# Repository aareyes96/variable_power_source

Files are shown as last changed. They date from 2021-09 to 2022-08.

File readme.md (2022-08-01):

# Variable Power Source

An essential tool in an electronics workshop is a Variable Power Source. This must regulate current and voltage delivered in addition to having protections against short circuits.

This Variable Power Supply is built by modifying an old PC ATX power supply and based on a tutorial made by Cuban electronics [here](http://cubaelectronica.blogspot.com/2017/06/hacer-fuente-atx-pc-variable-desde-1-28.html) where the modifications that need to be made to the PC ATX Power Supply are explained.

>### _**Here the microcontroller control board is made to achieve better control precision. It also provides a real-time current, voltage and power measurement.**_

## Features

* Complete range ( from 0V to 30V and 0A to 15A ) control with a maximum precision for a wide range.
* Fast short-circuit protection.
* Minimum modifications made to ATX Power Supply.
* Nice and clear interface.
* ~~5V (of Standby supply) for USB plug~~ (Not supported yet).
* small design (all into ATX chassis) by choice.

## What do you need ?

* Bluepill (STM32F103C8T6 microcontroller based board).
* OLED 128x64 0.96"(SSD1306 based)  ~~display or LCD 16x2 Display~~(Actually not supported).
* A rotary encoder with central Button.
* LM324 IC.
* BD139 Transistor.
* Some others common components (Resistors and Capacitors, LEDs, Connectors, a little switch, etc).

## Softwares Used

* STM32CubeIDE 1.3.0 (Firmware and Debug).
* KiCAD (Schematic and PCB).
* NI Multisim 14.0 (Simulations).

## **Important Note**

>PCB layout is made to do at home (DIY). They are not optimized to manufacture with a PCB manufacturing company like JLCPCB or others.

## Preview

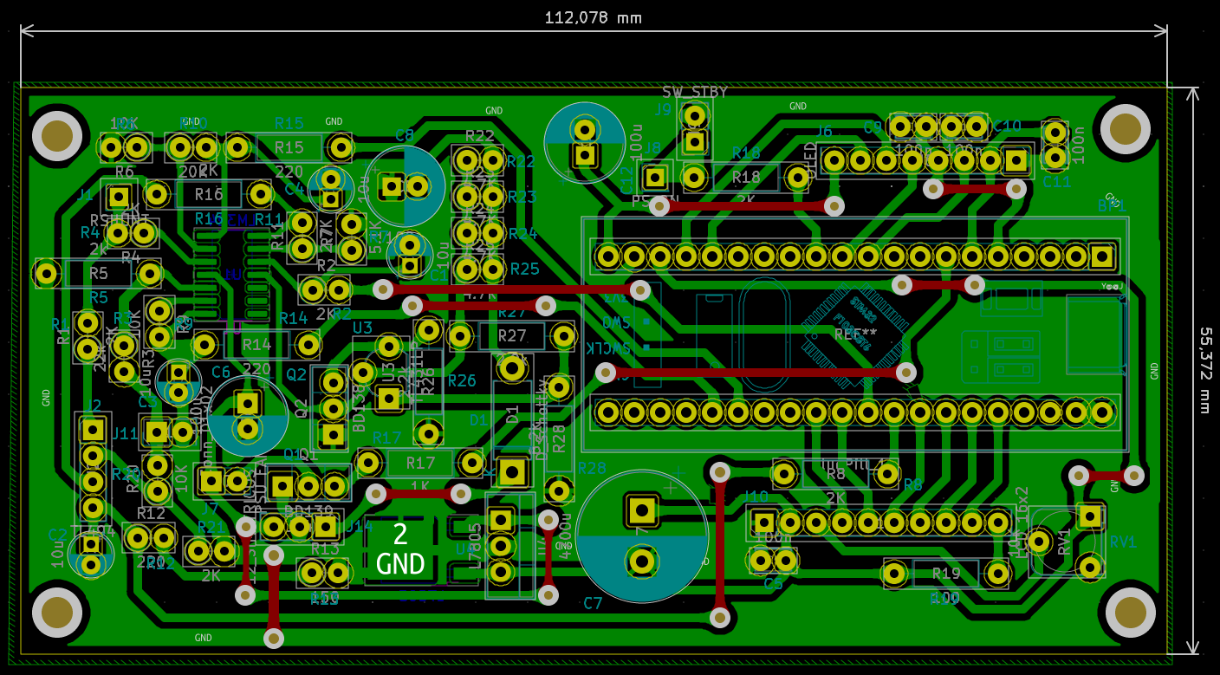
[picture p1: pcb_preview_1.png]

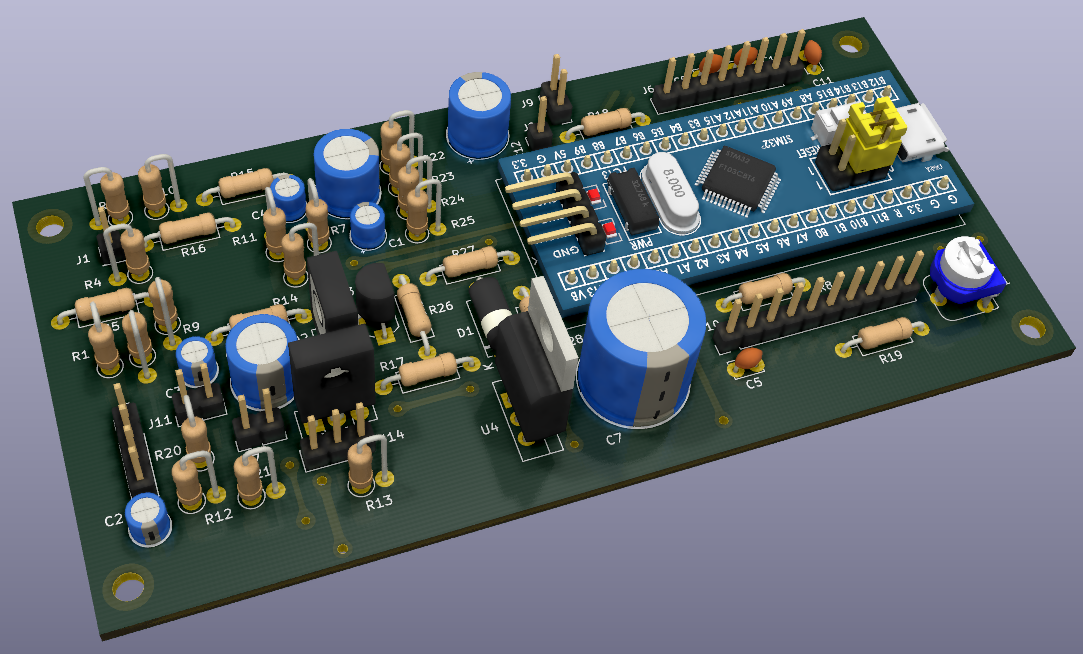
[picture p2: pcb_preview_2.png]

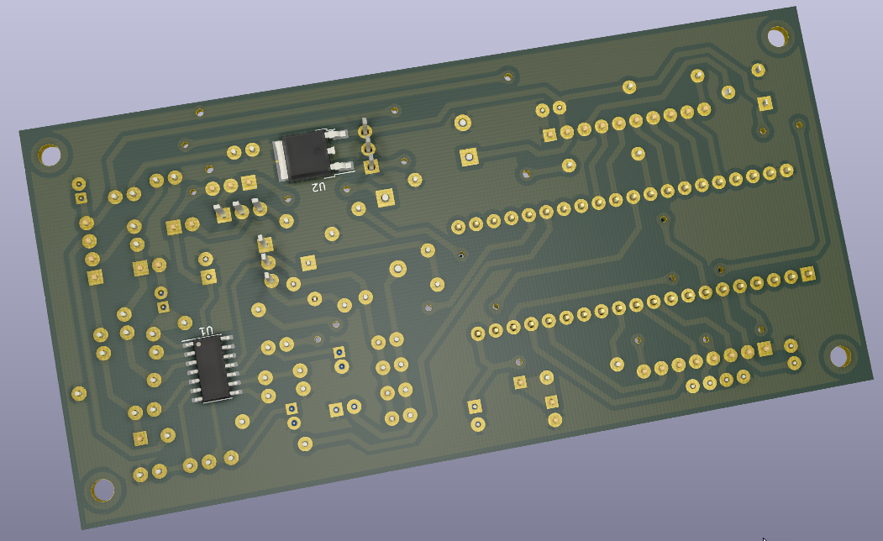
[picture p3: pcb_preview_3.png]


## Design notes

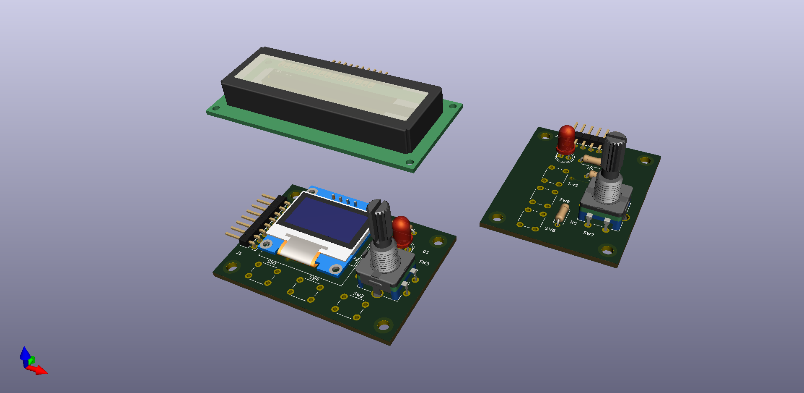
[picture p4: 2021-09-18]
PSU_displays/encoder.png

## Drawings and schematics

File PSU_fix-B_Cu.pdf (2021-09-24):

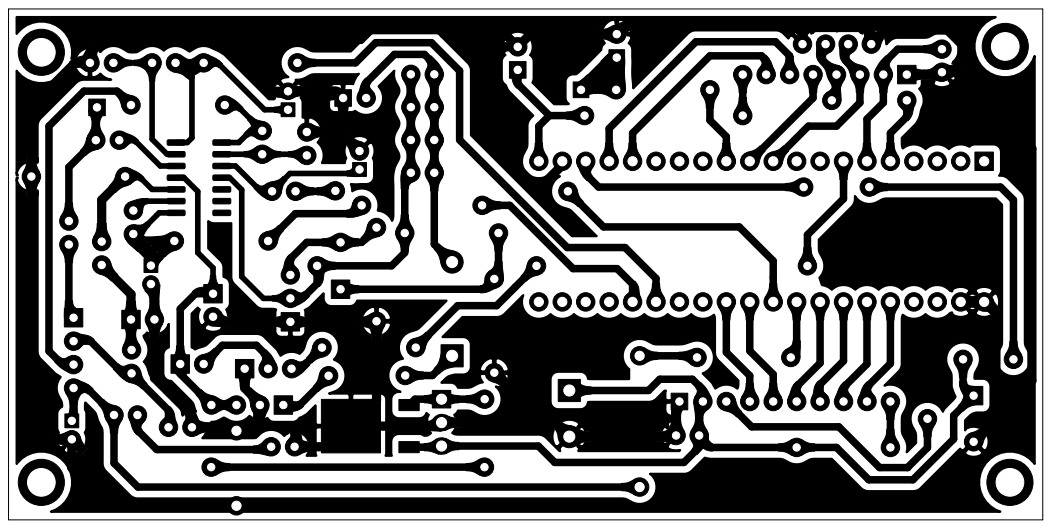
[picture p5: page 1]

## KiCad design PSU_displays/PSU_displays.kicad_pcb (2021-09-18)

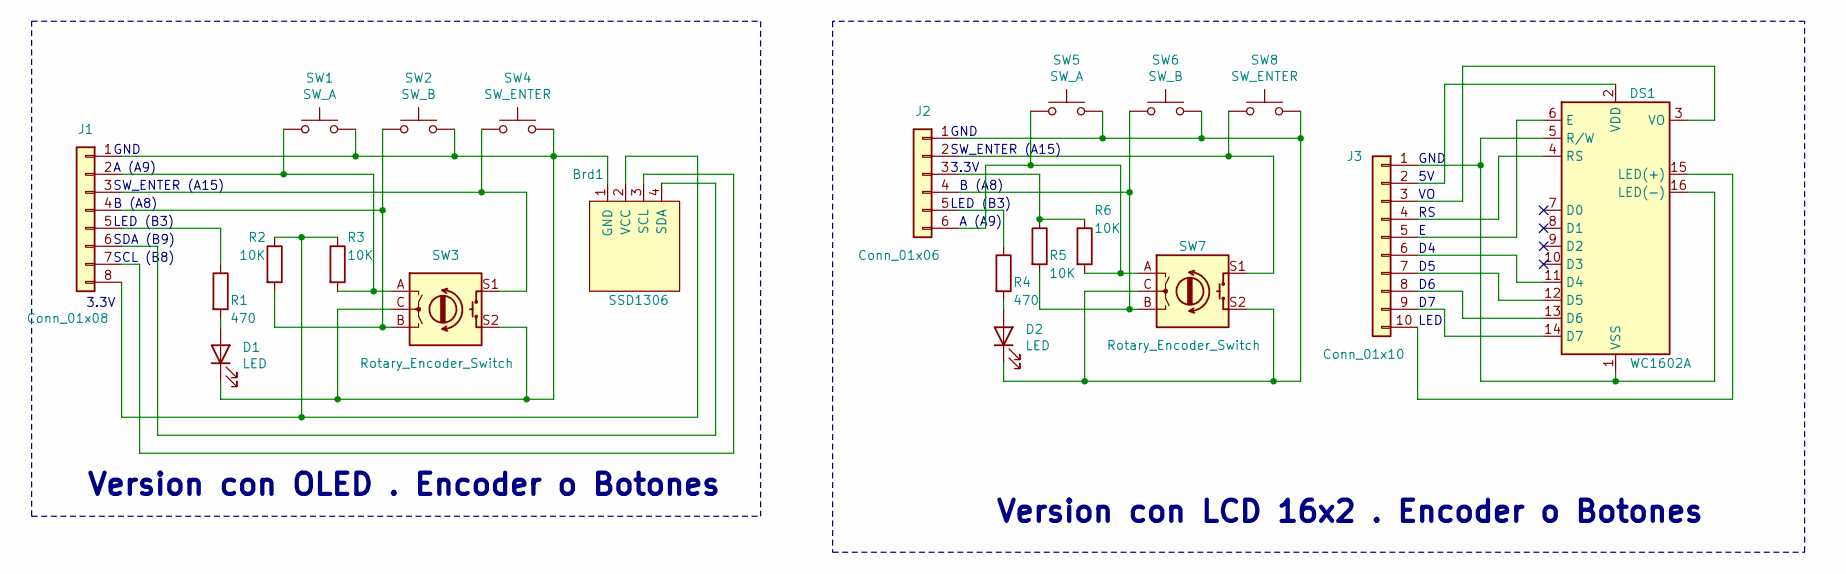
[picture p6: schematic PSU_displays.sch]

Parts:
Brd1: SSD1306; 128x64OLED
D1, D2: LED; LED_D5.0mm
DS1: WC1602A
J1: Conn_01x08; PinHeader_1x08_P2.54mm_Horizontal
J2: Conn_01x06; PinHeader_1x06_P2.54mm_Horizontal
J3: Conn_01x10; PinHeader_1x10_P2.54mm_Horizontal
R1, R4: 470; R_Axial_DIN0207_L6.3mm_D2.5mm_P7.62mm_Horizontal
R2, R3, R5, R6: 10K; R_Axial_DIN0207_L6.3mm_D2.5mm_P7.62mm_Horizontal
SW1, SW5: SW_A; SW_PUSH_6mm
SW2, SW6: SW_B; SW_PUSH_6mm
SW3, SW7: Rotary_Encoder_Switch; RotaryEncoder_Alps_EC11E-Switch_Vertical_H20mm_CircularMoun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
SW4, SW8: SW_ENTER; SW_PUSH_6mm

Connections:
unnamed: Brd1.1 (GND), D1.1 (K), J1.1, SW1.2, SW2.2, SW3.C, SW3.S2, SW4.2
unnamed: Brd1.2 (VCC), J1.8, R2.1, R3.1
unnamed: Brd1.3 (SCL), J1.7
unnamed: Brd1.4 (SDA), J1.6
unnamed: D1.2 (A), R1.2
unnamed: D2.1 (K), J2.1, SW5.2, SW6.2, SW7.C, SW7.S2, SW8.2
unnamed: D2.2 (A), R4.2
unnamed: DS1.1 (VSS), DS1.5 (R/W), DS1.16 (LED(-)), J3.1
unnamed: DS1.2 (VDD), J3.2
unnamed: DS1.3 (VO), J3.3
unnamed: DS1.4 (RS), J3.4
unnamed: DS1.6 (E), J3.5
unnamed: DS1.11 (D4), J3.6
unnamed: DS1.12 (D5), J3.7
unnamed: DS1.13 (D6), J3.8
unnamed: DS1.14 (D7), J3.9
unnamed: DS1.15 (LED(+)), J3.10
unnamed: J1.2, R3.2, SW1.1, SW3.A
unnamed: J1.3, SW3.S1, SW4.1
unnamed: J1.4, R2.2, SW2.1, SW3.B
unnamed: J1.5, R1.1
unnamed: J2.2, SW7.S1, SW8.1
unnamed: J2.3, R5.1, R6.1
unnamed: J2.4, R5.2, SW6.1, SW7.B
unnamed: J2.5, R4.1
unnamed: J2.6, R6.2, SW5.1, SW7.A

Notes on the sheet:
Version con OLED . Encoder o Botones
Version con LCD 16x2 . Encoder o Botones
3.3V
SCL (B8)
LED (B3)
B (A8)
SW_ENTER (A15)
A (A9)
GND
LED
SDA (B9)

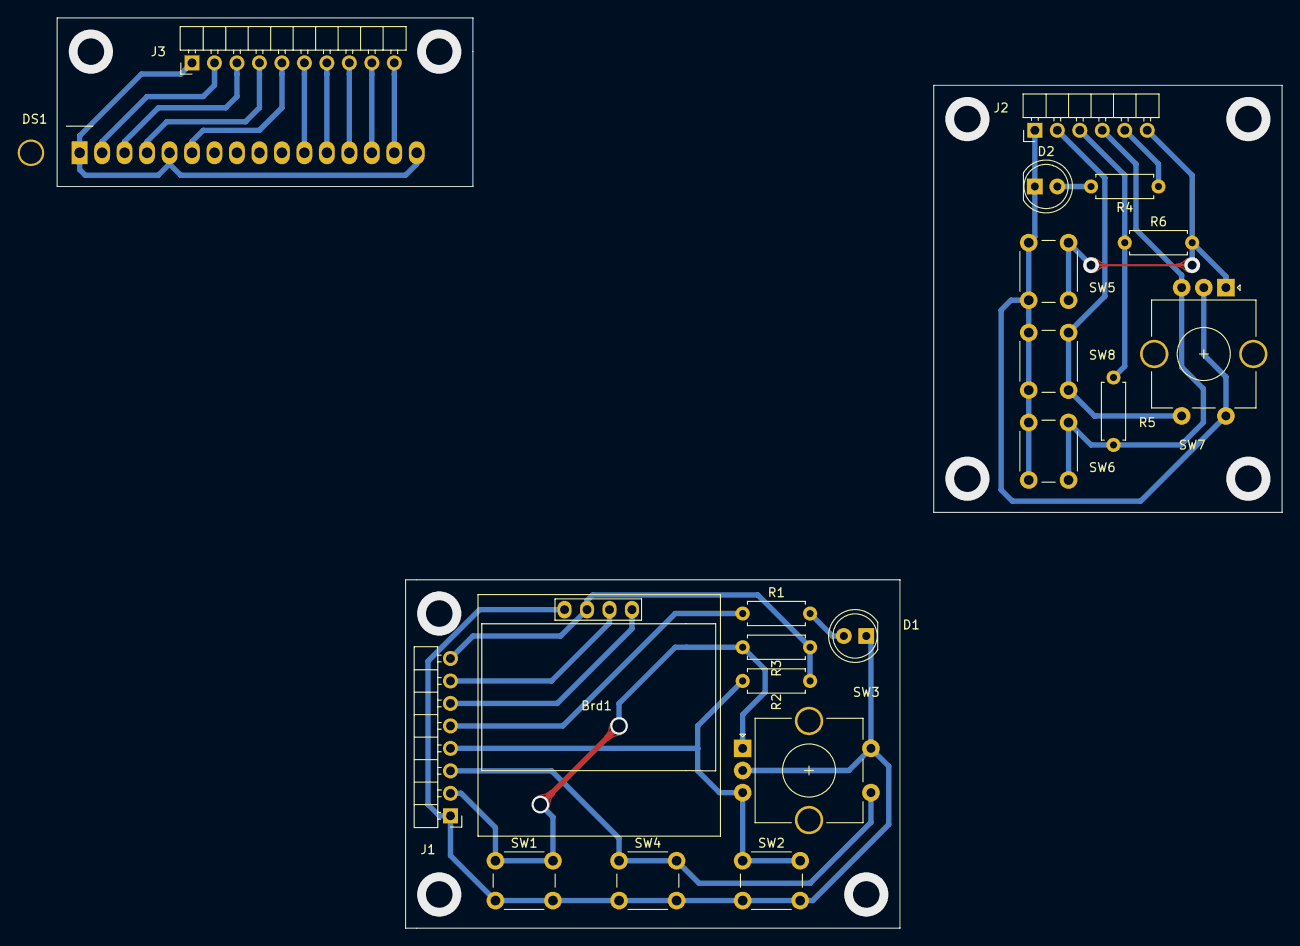
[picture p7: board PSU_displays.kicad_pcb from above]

Board: 2 copper layers, 138.4 x 102.9 mm, 21 parts (0 on the bottom side), 26 nets.

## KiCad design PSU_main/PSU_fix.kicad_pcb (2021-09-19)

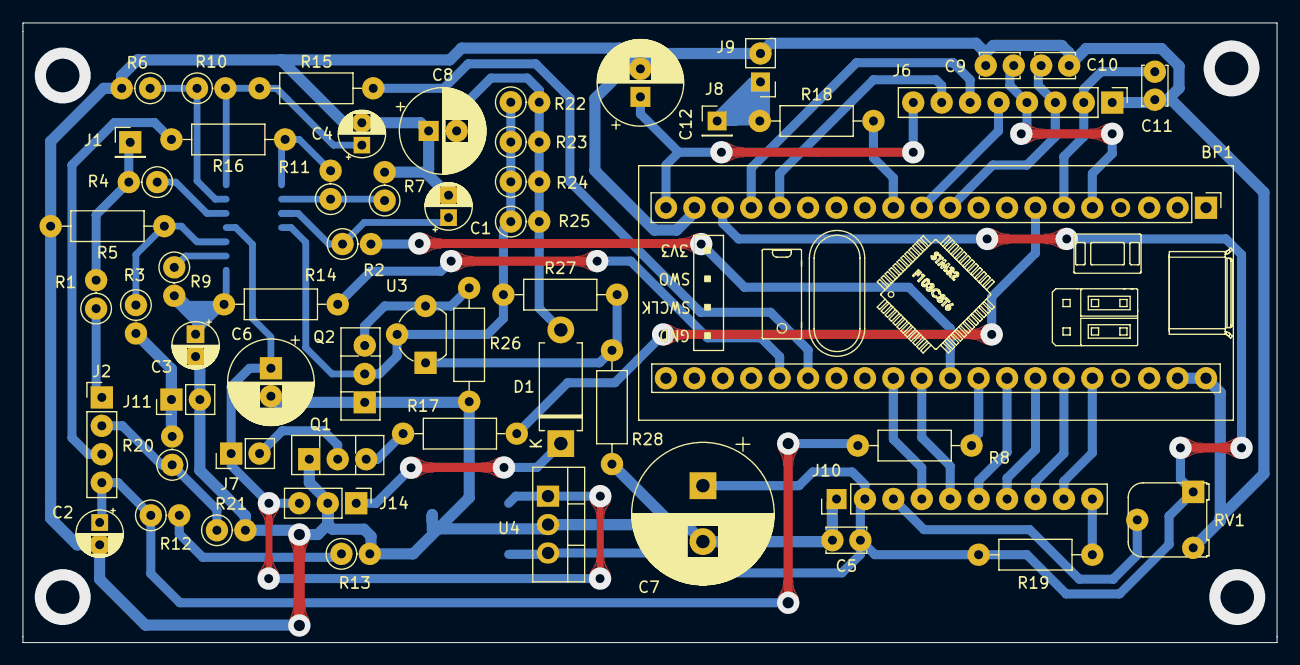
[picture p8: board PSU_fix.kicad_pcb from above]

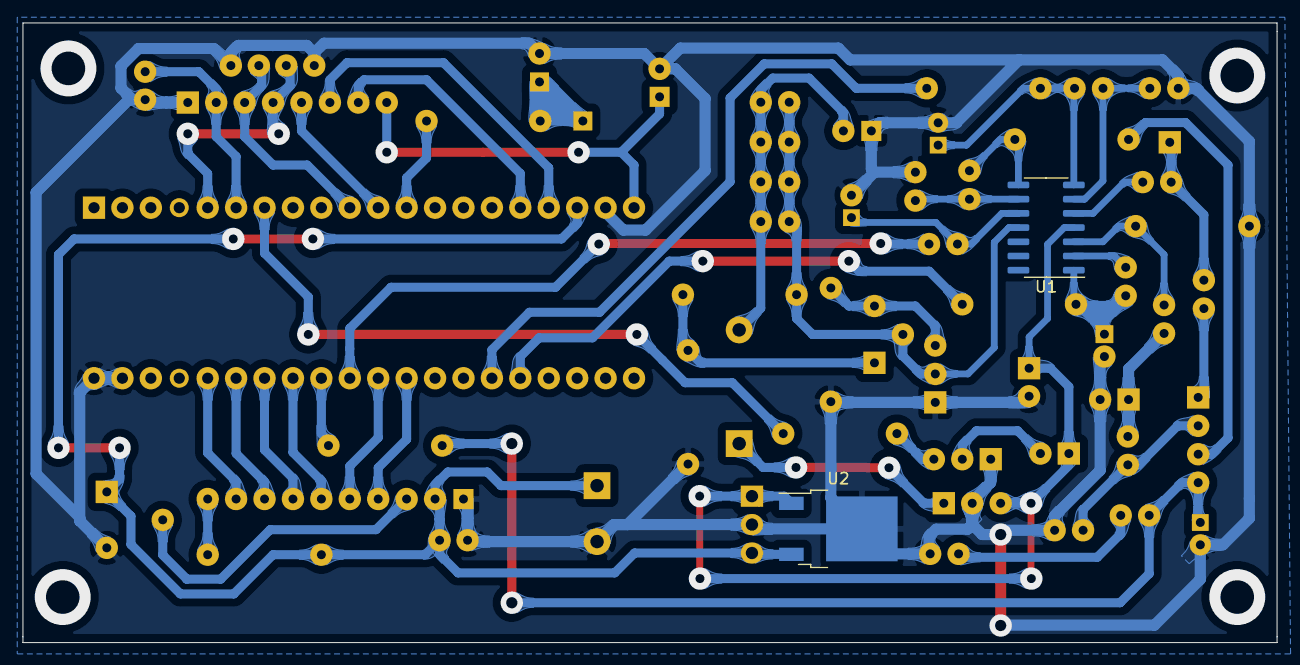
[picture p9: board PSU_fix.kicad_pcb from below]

Board: 2 copper layers, 112.1 x 55.4 mm, 58 parts (2 on the bottom side), 48 nets.

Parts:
BP1: BluePill_1; YAAJ_BluePill_1
C1, C2, C3, C4: 10u; CP_Radial_D4.0mm_P2.00mm
C5, C9, C10, C11: 100n; C_Disc_D3.4mm_W2.1mm_P2.50mm
C6, C8, C12: 100u; CP_Radial_D7.5mm_P2.50mm
C7: 4700u; CP_Radial_D12.5mm_P5.00mm
D1: D_Schottky; D_DO-15_P10.16mm_Horizontal
J1: RSHUNT; PinHeader_1x01_P2.54mm_Vertical
J2: TL494; PinHeader_1x04_P2.54mm_Vertical
J6: OLED; PinHeader_1x08_P2.54mm_Vertical
J7: PSU FAN; PinHeader_1x02_P2.54mm_Vertical
J8: PS_ON; PinHeader_1x01_P2.54mm_Vertical
J9: SW_STBY; PinHeader_1x02_P2.54mm_Vertical
J10: LCD 16x2; PinHeader_1x10_P2.54mm_Vertical
J11: Conn_01x02; PinHeader_1x02_P2.54mm_Vertical
J14: 12_SIMETRICOS; PinHeader_1x03_P2.54mm_Vertical
Q1: BD139; TO-126-3_Vertical
Q2: BD138; TO-126-3_Vertical
R1, R2, R4, R21: 2K; R_Axial_DIN0207_L6.3mm_D2.5mm_P2.54mm_Vertical
R3: 22k; R_Axial_DIN0207_L6.3mm_D2.5mm_P2.54mm_Vertical
R5: 2k; R_Axial_DIN0207_L6.3mm_D2.5mm_P10.16mm_Horizontal
R6, R9, R20: 10K; R_Axial_DIN0207_L6.3mm_D2.5mm_P2.54mm_Vertical
R7: 5.1K; R_Axial_DIN0207_L6.3mm_D2.5mm_P2.54mm_Vertical
R8, R16, R18: 2K; R_Axial_DIN0207_L6.3mm_D2.5mm_P10.16mm_Horizontal
R10: 20K; R_Axial_DIN0207_L6.3mm_D2.5mm_P2.54mm_Vertical
R11: 2.7K; R_Axial_DIN0207_L6.3mm_D2.5mm_P2.54mm_Vertical
R12: 220; R_Axial_DIN0207_L6.3mm_D2.5mm_P2.54mm_Vertical
R13: 150; R_Axial_DIN0207_L6.3mm_D2.5mm_P2.54mm_Vertical
R14, R15: 220; R_Axial_DIN0207_L6.3mm_D2.5mm_P10.16mm_Horizontal
R17: 1K; R_Axial_DIN0207_L6.3mm_D2.5mm_P10.16mm_Horizontal
R19: 100; R_Axial_DIN0207_L6.3mm_D2.5mm_P10.16mm_Horizontal
R22, R23, R24, R25: 4.7K; R_Axial_DIN0207_L6.3mm_D2.5mm_P2.54mm_Vertical
R26, R27: 2.2k; R_Axial_DIN0207_L6.3mm_D2.5mm_P10.16mm_Horizontal
R28: 8.2k; R_Axial_DIN0207_L6.3mm_D2.5mm_P10.16mm_Horizontal
RV1: 10K; Potentiometer_Runtron_RM-065_Vertical
U1: LM324; SOIC-14_3.9x8.7mm_P1.27mm
U2: L7805; TO-252-2
U3: TL431LP; TO-92_Wide
U4: L7805; TO-220-3_Vertical

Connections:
+5V: BP1.18, C5.1, C7.1, J10.2, R19.1, RV1.1, U2.3, U4.3
+12V: C6.1, J7.1, J14.3, U1.4, U2.1, U4.1
-12V: Q2.2, R22.1, R23.1, R24.1, R25.1, R27.1, U1.11, U3.2
/PIN_1_TL494: J2.2, R20.1, R21.1
/PIN_2_TL494: J2.3, R16.2
/PIN_15_TL494: C2.1, J2.4, R8.1, R12.1
/PIN_16_TL494: J2.1, R1.1
A0: BP1.25, R14.2
A1: BP1.26, R15.2
A6: BP1.31, R2.2
A7: BP1.32, R8.2
A10: BP1.7, R17.2
B4: BP1.12, R18.2
GND: BP1.19, BP1.39, BP1.40, C1.2, C2.2, C3.2, C4.2, C5.2, C6.2, C7.2, C8.1, C9.1, C10.2, C11.1, C12.2, J6.1, J9.2, J10.1, J11.2, J14.2, Q1.1, Q2.1, R5.2, R6.2, R7.2, R13.2, R21.2, R26.2, R28.2, RV1.3, U2.2, U4.2
unnamed: BP1.5, C9.2, J6.4
unnamed: BP1.6, C11.2, J6.2
unnamed: BP1.10, C10.1, J6.3
unnamed: BP1.11, J6.5
unnamed: BP1.16, J6.7
unnamed: BP1.17, J6.6
unnamed: BP1.20, C12.1, J6.8
unnamed: BP1.29, J10.4
unnamed: BP1.30, J10.5
unnamed: BP1.33, J10.6
unnamed: BP1.34, J10.7
unnamed: BP1.35, J10.8
unnamed: BP1.36, J10.9
unnamed: C1.1, R2.1, U1.10
unnamed: C3.1, R9.2, R14.1, U1.1
unnamed: C4.1, R10.2, R15.1, U1.7
unnamed: C8.2, D1.2, R22.2, R23.2, R24.2, R25.2
unnamed: D1.1, J14.1
unnamed: J1.1, R1.2, R4.2
unnamed: J7.2, Q1.2
unnamed: J8.1, J9.1, R18.1
unnamed: J10.3, RV1.2
unnamed: J10.10, R19.2
unnamed: Q1.3, R17.1
unnamed: Q2.3, R26.1, U3.3
unnamed: R3.1, R5.1, U1.3
unnamed: R4.1, U1.5
unnamed: R9.1, U1.2
unnamed: R6.1, R10.1, U1.6
unnamed: R7.1, R11.1, U1.9
unnamed: R11.2, R16.1, U1.8
unnamed: R12.2, R13.1
unnamed: R27.2, R28.1, U3.1
Vout: J11.1, R3.2, R20.2

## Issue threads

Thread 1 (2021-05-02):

README missing (and compile instructions)

stdevPavelmc, 2021-05-02:
The README.md file is missing describing the project goal and details.

On the details you must explain the framework you used and compile instructions.

Closed 2021-05-03.

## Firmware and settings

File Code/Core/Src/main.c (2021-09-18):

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

/* Includes ------------------------------------------------------------------*/
#include "main.h"

/* USER CODE BEGIN Includes */
#include "fonts.h"
#include "ssd1306.h"
#include "test.h"
#include <stdio.h>
/* USER CODE END Includes */

ADC_HandleTypeDef hadc1;
DMA_HandleTypeDef hdma_adc1;

I2C_HandleTypeDef hi2c1;

TIM_HandleTypeDef htim1;
TIM_HandleTypeDef htim3;

void SystemClock_Config(void);
static void MX_GPIO_Init(void);
static void MX_DMA_Init(void);
static void MX_ADC1_Init(void);
static void MX_I2C1_Init(void);
static void MX_TIM1_Init(void);
static void MX_TIM3_Init(void);
/* USER CODE BEGIN PFP */

void encoder_it(void);
void button_it(void);
void display_oled(void);
void read_values(void);
void control(void);
/* USER CODE END PFP */

/* USER CODE BEGIN 0 */
  uint32_t a=0;
  char as[15];
  uint8_t e=0;
  float volt=0;
  float corr=0;
  uint16_t _volt=0;
  uint16_t _corr=0;
  uint8_t flag=0;
  uint32_t readed_adc[3];
  uint64_t __readed_adc[3];
  uint32_t _readed_adc[3];
  float val=0;
  float val1=0;
  uint16_t set_corr=0;
  float VREFINT_VAL =0;
  float volts =0;
  uint8_t contador=0;

  void HAL_ADC_ConvCpltCallback(ADC_HandleTypeDef* hadc)
  {
    if(hadc->Instance == ADC1)
	{
    	contador++;
	  for(int i=0; i<3;i++)
	  {
      __readed_adc[i] += _readed_adc[i];
	  }
	  if(contador == 10)
	  {
		  contador=0;
		  readed_adc[0] = __readed_adc[0] / 10;
		  readed_adc[1] = __readed_adc[1] / 10;
		  readed_adc[2] = __readed_adc[2] / 10;
	   VREFINT_VAL= (1.2000/readed_adc[2])*4095.000;

	   __readed_adc[0]=0;
	   __readed_adc[1]=0;
	   __readed_adc[2]=0;
	  }
	}
  }
/* USER CODE END 0 */

/**
  * @brief  The application entry point.
  * @retval int
  */
int main(void)
{
  /* MCU Configuration--------------------------------------------------------*/

  /* Reset of all peripherals, Initializes the Flash interface and the Systick. */
  HAL_Init();

  /* Configure the system clock */
  SystemClock_Config();

  /* Initialize all configured peripherals */
  MX_GPIO_Init();
  MX_DMA_Init();
  MX_ADC1_Init();
  MX_I2C1_Init();
  MX_TIM1_Init();
  MX_TIM3_Init();
  /* USER CODE BEGIN 2 */


  HAL_ADCEx_Calibration_Start(&hadc1);

  HAL_TIM_PWM_Start(&htim3, TIM_CHANNEL_1);
  HAL_TIM_PWM_Start(&htim3, TIM_CHANNEL_2);

  HAL_TIM_Encoder_Start_IT(&htim1, TIM_CHANNEL_ALL);

  SSD1306_Init();

  HAL_ADC_Start_DMA(&hadc1, _readed_adc, 3);
  /* USER CODE END 2 */

  /* Infinite loop */
  /* USER CODE BEGIN WHILE */
  while (1)
  {
    /* USER CODE END WHILE */

    /* USER CODE BEGIN 3 */

	read_values();
	control();
	/*if(volt <= 2.08) val1 =volt+0.400;
	if(volt >2.08  && volt <=3.008 )val1 =volt+0.300;
	if(volt >3.08  && volt <=4.08 )val1 =volt+0.200;
	if(volt >4.08  && volt <=5.00 )val1 =volt+0.100;

	if(volt >6.00  && volt <=7.00 )val1 =volt-0.100;
	if(volt >7.00  && volt <=8.20 )val1 =volt-0.200;
	if(volt >8.30  && volt <=9.60 )val1 =volt-0.300;
	if(volt >9.60  && volt <=10.40 )val1 =volt-0.400;
	if(volt >10.40  && volt <=12.00 )val1 =volt-0.500;
	if(volt >12.00  && volt <=14.50 )val1 =volt-0.600;
	if(volt >14.50  && volt <=15.00 )val1 =volt-0.900;
	if(volt >15.00  && volt <=19.00 )val1 =volt-1.000;
	if(volt >19.00  && volt <=22.50 )val1 =volt-1.300;
	if(volt >22.50  && volt <=25.00 )val1 =volt-1.700;
	if(volt >25.00  && volt <=28.00 )val1 =volt-2.000;
	if(volt >28.00  )val1 =volt-2.300;*/
	val1 =volt;
	val  =corr;
	display_oled();

	if(val >0)HAL_GPIO_WritePin(FAN_GPIO_Port, FAN_Pin, 1);
	else HAL_GPIO_WritePin(FAN_GPIO_Port, FAN_Pin, 0);
	if(val1 >0.5)HAL_GPIO_WritePin(LED_GPIO_Port, LED_Pin, 1);
		else HAL_GPIO_WritePin(LED_GPIO_Port, LED_Pin, 0);
	HAL_Delay(500);

  }
  /* USER CODE END 3 */
}

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
/* USER CODE BEGIN 4 */

void control(void)
{
  TIM3->CCR1 = _volt;
  TIM3->CCR2 = _corr;

}
void read_values(void)
{

	 //VREFINT_VAL= (1.2000/readed_adc[5])*4095.000;

  volt = (readed_adc[0]*(3.300/4096.0000))/0.083;
  corr = (readed_adc[1]*(3.300/4096.0000))/0.15000;

}

void encoder_it(void)
{
  //a=(TIM1->CNT)>>2;

  if(flag==0) _volt = ((TIM1->CNT)>>2);
  if(flag==0xFF) _corr = ((TIM1->CNT)>>2);
}

void button_it(void)
{
  flag = ~flag;

  if(flag==0) TIM1->CNT = (_volt<<2);
  if(flag==0xFF) TIM1->CNT = (_corr<<2);
}

void display_oled(void)
{

  //SSD1306_Clear();
  SSD1306_GotoXY(00, 1);

  sprintf(as,"%05.2f V",val1);
  SSD1306_Puts(as, &Font_16x26, 1);
  if (flag == 0) SSD1306_Puts("<", &Font_11x18, 1);
  else SSD1306_Puts(" ", &Font_11x18, 1);
  SSD1306_GotoXY(0, 27);
  sprintf(as,"%05.2f A",val);
  SSD1306_Puts(as, &Font_16x26, 1);

  SSD1306_GotoXY(0, 53);
  sprintf(as,"SET:%05.2fA",_corr*0.014662);
  if (flag == 0xFF) SSD1306_Puts(as, &Font_7x10, 0);
  else SSD1306_Puts(as, &Font_7x10, 1);

  sprintf(as," %06.2fW",val1*val);
  SSD1306_Puts(as, &Font_7x10, 1);
  SSD1306_UpdateScreen();

}
/* USER CODE END 4 */
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


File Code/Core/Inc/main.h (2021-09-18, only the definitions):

#define LCD_RS_Pin GPIO_PIN_4
#define LCD_RS_GPIO_Port GPIOA
#define LCD_E_Pin GPIO_PIN_5
#define LCD_E_GPIO_Port GPIOA
#define LCD_D4_Pin GPIO_PIN_0
#define LCD_D4_GPIO_Port GPIOB
#define LCD_D5_Pin GPIO_PIN_1
#define LCD_D5_GPIO_Port GPIOB
#define LCD_D6_Pin GPIO_PIN_10
#define LCD_D6_GPIO_Port GPIOB
#define LCD_D7_Pin GPIO_PIN_11
#define LCD_D7_GPIO_Port GPIOB
#define FAN_Pin GPIO_PIN_10
#define FAN_GPIO_Port GPIOA
#define Button_Pin GPIO_PIN_15
#define Button_GPIO_Port GPIOA
#define Button_EXTI_IRQn EXTI15_10_IRQn
#define LED_Pin GPIO_PIN_3
#define LED_GPIO_Port GPIOB

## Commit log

2021-05-03 fix pcb errors and add identity mask
    [variable_power_source.kicad_pcb]
2021-05-03 relocate and short files
    [main.c, main.h, variable_power_source.ioc]
2021-09-18 updates and fixes
    [PSU_displays.kicad_pcb, PSU_displays.sch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]
2021-09-19 fix some things
    [PSU_displays.kicad_pcb, PSU_displays.sch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]

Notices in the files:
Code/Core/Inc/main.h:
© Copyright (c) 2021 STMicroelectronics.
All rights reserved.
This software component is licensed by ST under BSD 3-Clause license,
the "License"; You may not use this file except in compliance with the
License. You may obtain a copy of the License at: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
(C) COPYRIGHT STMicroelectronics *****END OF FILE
